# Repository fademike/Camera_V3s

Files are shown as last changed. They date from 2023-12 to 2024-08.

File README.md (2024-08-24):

# Camera_V3s
Webcam based on allwinner V3s and ESP8089

Simple 2 side board with Allwinner V3s, ov2640 and esp8089! 
(I didn't check the sound)

# How it works
Change wifi settings in file CONFIG_FILE <br>
Find ip in network by name. For example fing app: Image alt
<br>
Watch the video on the MXPlayer(rtsp://192.168.10.22:8554/test), ffmpeg (ffplay -i rtsp://192.168.10.22:8554/test).. <br>
Watch the video on the Gstreamer: gst-launch-1.0 rtspsrc location="rtsp://192.168.10.22:8554/test" latency=0 ! rtph264depay ! decodebin ! videoconvert ! ximagesink <br>

# for QGroundControl:
TX: gst-launch-1.0 -v v4l2src device=/dev/video0 ! "video/x-raw,format=UYVY,width=800,height=600,framerate=10/1" ! videoconvert ! cedar_h264enc bitrate=2000 qp=15 keyint=10 ! rtph264pay pt=96 ! udpsink host=192.168.10.14 port=5600 <br>
RX on QGC or gstreamer: gst-launch-1.0 -v udpsrc port=5600 ! "application/x-rtp, media=(string)video, clock-rate=(int)90000, encoding-name=(string)H264, payload=(int)96" ! rtph264depay ! h264parse ! avdec_h264 ! videoconvert ! autovideosink <br>

v1.4 changed scheme and pcb. didn't check <br>
v1.2 in the previous commit. it works but there are errors errataSheet.txt in kicad

top             |  bottom
:-------------------------:|:-------------------------:
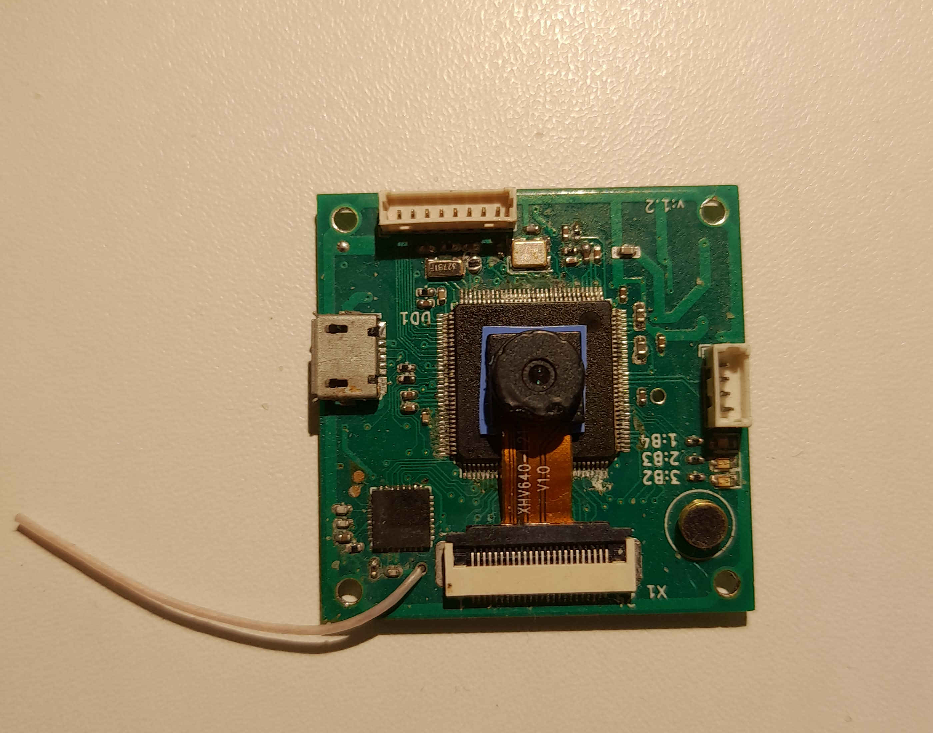
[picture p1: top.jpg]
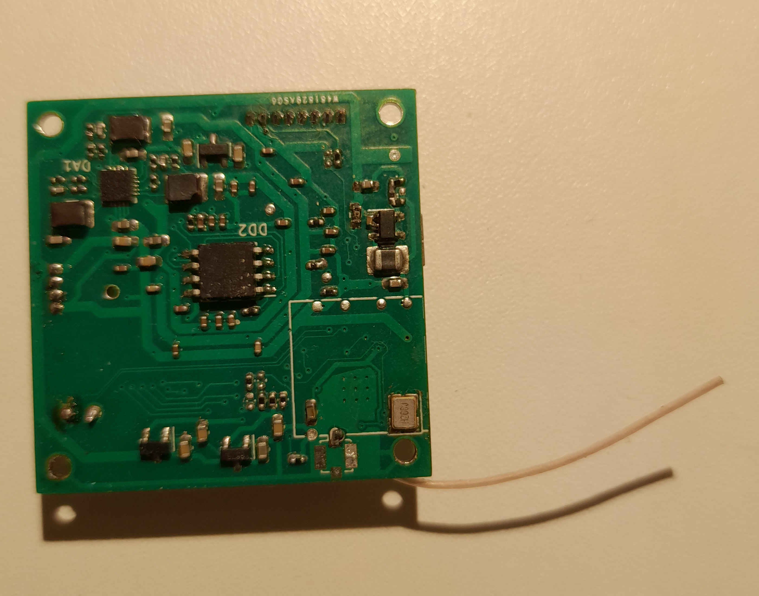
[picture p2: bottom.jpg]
  |  

# How to build

git clone https://github.com/fademike/buildroot_v3s.git <br>
tar xf ~/Downloads/buildroot-2023.08.tar.xz <br>
cd buildroot-2023.08 <br>
ln -s ~/Downloads/buildroot/dl ./dl  # if you want <br>
make BR2_EXTERNAL=../buildroot_v3s licheepi_zero_defconfig (in dts you can change size of NOR flash) <br>
make <br>
make esp-rebuild && make <br>

# How to install

insert sd card.. <br>
./make_sd.sh <br>
run board camera_v3s from flash <br>
mount /dev/mmcblk0p1 /mnt <br>
flashcp /mnt/uboot_spi.bin /dev/mtd0 -v <br>
flashcp /mnt/zImage /dev/mtd1 -v <br>
flashcp /mnt/uboot_spi.bin /dev/mtd2 -v <br>
flashcp /mnt/rootfs.squashfs /dev/mtd3 -v <br>
flash_erase /dev/mtd4 0 1000.. <br>
add to mtd4 CONFIG_FILE to wifi settings, and init/deinit script of system <br>
init.sh script for example: <br>
test-launch  --gst-debug=3 '( v4l2src device=/dev/video0 ! video/x-raw,format=UYVY,width=800,height=600,framerate=10/1 ! videoconvert ! cedar_h264enc bitrate=2000 qp=15 keyint=10 ! rtph264pay name=pay0 pt=96 )' &

# note

The wi-fi is crashes after 30-50min. It was discussed on the forum (https://whycan.com/t_4326.html). I would like to change it to XR819, 88W8801 or others. 
You can connect usb wifi adapter (such as MT7601U) or solder a USB wifi module on bottom side.
I didn't notice any problems with the usb wifi adapter.

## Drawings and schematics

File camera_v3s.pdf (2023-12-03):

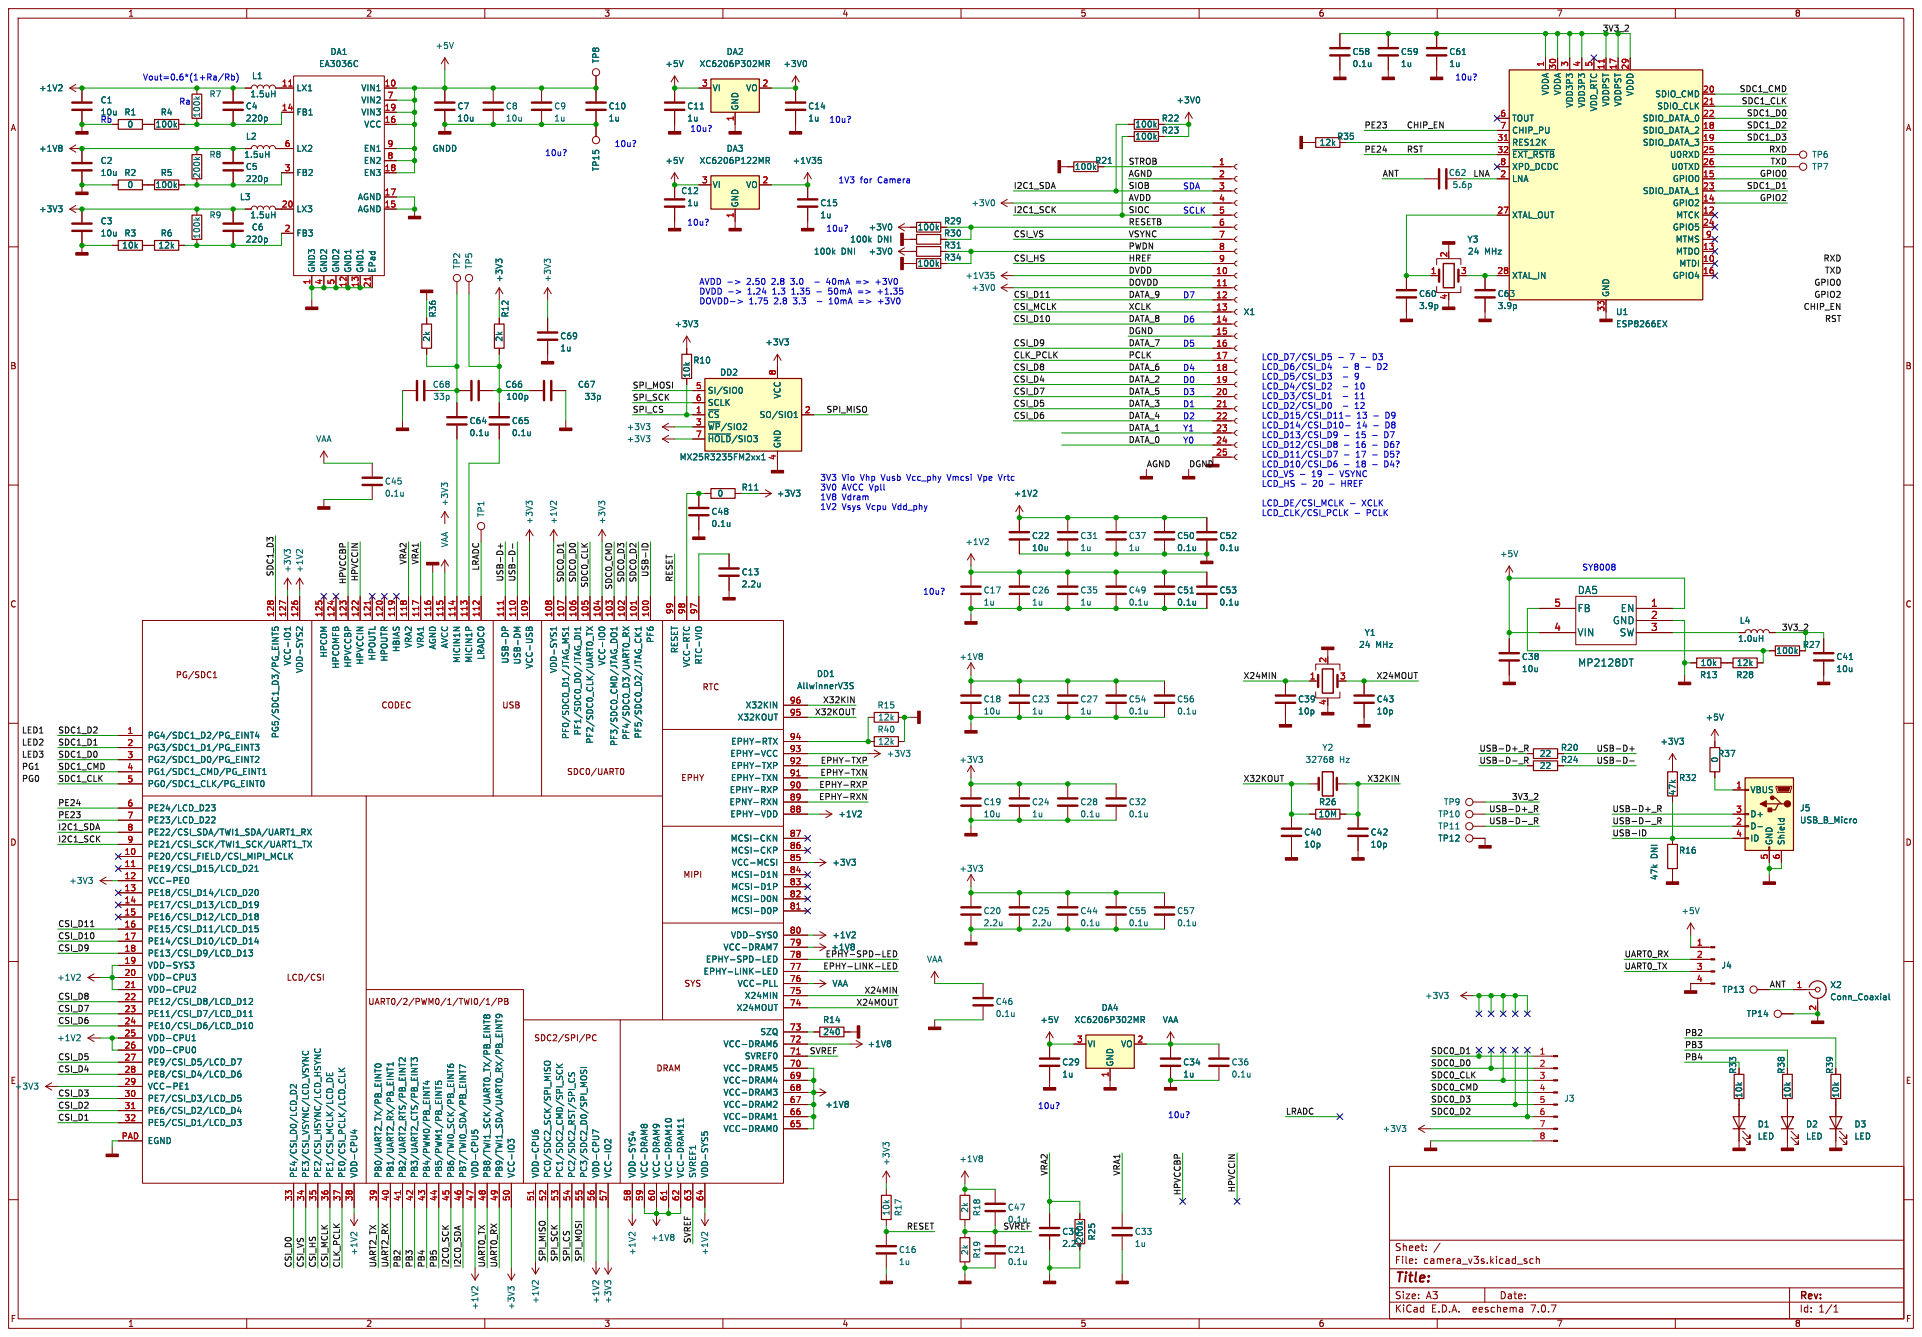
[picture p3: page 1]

4 SI/SIO0 5 SCLK 6 ~{HOLD}/SIO3 7 VCC

3V3 Vio Vhp Vusb Vcc_phy Vmcsi Vpe Vrtc 3V0 AVCC Vpll 1V8 Vdram

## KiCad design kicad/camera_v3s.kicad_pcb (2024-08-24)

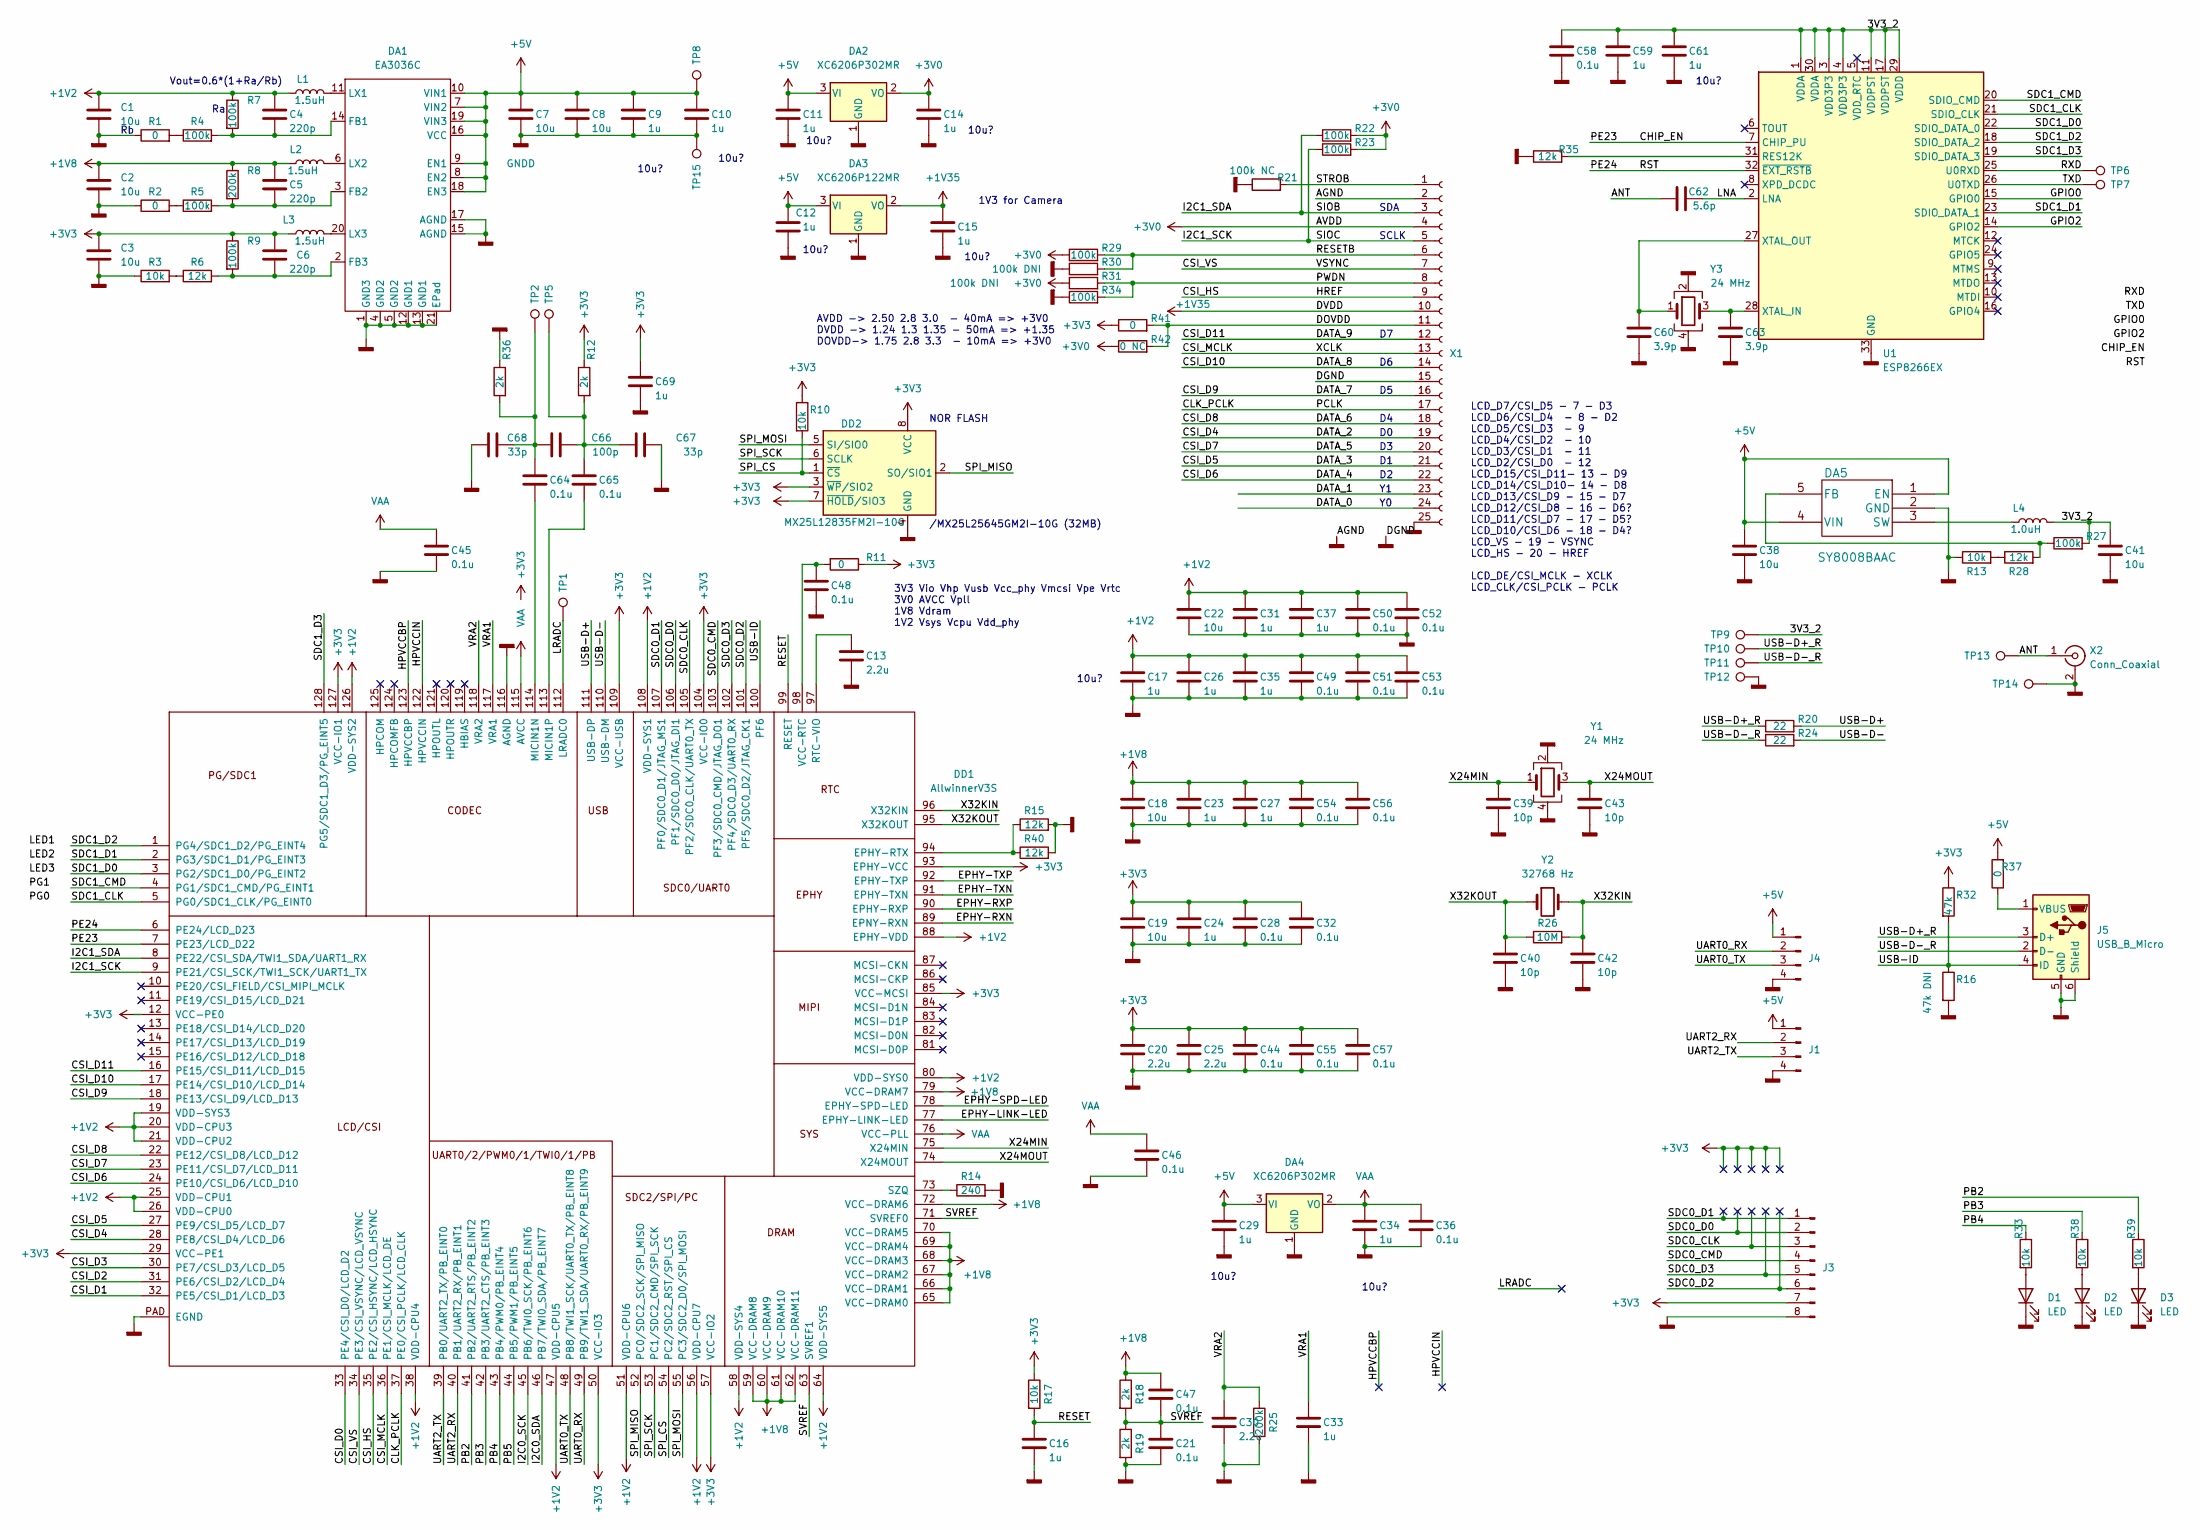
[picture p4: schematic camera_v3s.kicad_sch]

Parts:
C1, C2, C3, C7, C8, C18, C19, C22, C38, C41: 10u; C_0603_1608Metric; Voltage 6.3V
C4, C5, C6: 220p; C_0402_1005Metric; Voltage 6.3V
C9, C10, C11, C12, C14, C15, C16, C17, C23, C24, C26, C27, C29, C31, C33, C34, C35, C37, C59, C61, C69: 1u; C_0402_1005Metric; Voltage 6.3V
C13, C20, C25, C30: 2.2u; C_0402_1005Metric; Voltage 6.3V
C21, C28, C32, C36, C44, C45, C46, C47, C48, C49, C50, C51, C52, C53, C54, C55, C56, C57, C58, C64, C65: 0.1u; C_0402_1005Metric; Voltage 6.3V
C39, C40, C42, C43: 10p; C_0402_1005Metric; Voltage 6.3V
C60, C63: 3.9p; C_0402_1005Metric; Voltage 6.3V
C62: 5.6p; C_0402_1005Metric; Voltage 6.3V
C66: 100p; C_0402_1005Metric; Voltage 6.3V
C67, C68: 33p; C_0402_1005Metric; Voltage 6.3V
D1, D2, D3: LED; LED_0603_1608Metric
DA1: EA3036C; QFN-20-1EP_3x3mm_P0.4mm_EP1.65x1.65mm
DA2, DA4: XC6206P302MR; SOT-23
DA3: XC6206P122MR; SOT-23
DA5: SY8008BAAC; SOT-23-5
DD1: AllwinnerV3S; LQFP-128_14x14mm_P0.4mm
DD2: MX25L12835FM2I-10G; SOP-8_5.28x5.23mm_P1.27mm
J1, J4: Conn_01x04_Male; Molex_PicoBlade_53047-0410_1x04_P1.25mm_Vertical
J3: Conn_01x08_Male; Molex_PicoBlade_53047-0810_1x08_P1.25mm_Vertical
J5: USB_B_Micro; USB_Micro-B_Molex_47346-0001
L1, L2, L3: 1.5uH; L_1210_3225Metric
L4: 1.0uH; L_1210_3225Metric
R1, R2, R11, R41: 0; R_0402_1005Metric
R3, R10, R13, R17, R33, R38, R39: 10k; R_0402_1005Metric
R4, R5, R7, R9, R22, R23, R27, R29, R34: 100k; R_0402_1005Metric
R6, R15, R28, R35, R40: 12k; R_0402_1005Metric
R8, R25: 200k; R_0402_1005Metric
R12, R18, R19, R36: 2k; R_0402_1005Metric
R14: 240; R_0402_1005Metric
R16: 47k DNI; R_0402_1005Metric
R20, R24: 22; R_0402_1005Metric
R21: 100k NC; R_0402_1005Metric
R26: 10M; R_0402_1005Metric
R30, R31: 100k DNI; R_0402_1005Metric
R32: 47k; R_0402_1005Metric
R37: 0; R_0603_1608Metric
R42: 0 NC; R_0402_1005Metric
TP1, TP2, TP5, TP6, TP7, TP8, TP9, TP10, TP11, TP12, TP13, TP14, TP15: TestPoint; TestPoint_Pad_D1.0mm
U1: ESP8266EX; QFN-32-1EP_5x5mm_P0.5mm_EP3.45x3.45mm
X1: Conn_01x25_Female; CONN_FPC_24_0.5
X2: Conn_Coaxial; U.FL_Molex_MCRF_73412-0110_Vertical
Y1, Y3: 24 MHz; Crystal_SMD_3225-4Pin_3.2x2.5mm
Y2: 32768 Hz; Crystal_SMD_3215-2Pin_3.2x1.5mm

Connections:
+1V2: C1.1, C4.1, C17.1, C22.1, C26.1, C31.1, C35.1, C37.1, C49.1, C50.1, C51.1, C52.1, C53.1, DD1.19 (VDD-SYS3), DD1.20 (VDD-CPU3), DD1.21 (VDD-CPU2), DD1.25 (VDD-CPU1), DD1.26 (VDD-CPU0), DD1.38 (VDD-CPU4), DD1.47 (VDD-CPU5), DD1.51 (VDD-CPU6), DD1.56 (VDD-CPU7), DD1.58 (VDD-SYS4), DD1.64 (VDD-SYS5), DD1.80 (VDD-SYS0), DD1.88 (EPHY-VDD), DD1.108 (VDD-SYS1), DD1.126 (VDD-SYS2), L1.1, R7.1
+1V8: C2.1, C5.1, C18.1, C23.1, C27.1, C47.1, C54.1, C56.1, DD1.59 (VCC-DRAM8), DD1.60 (VCC-DRAM9), DD1.61 (VCC-DRAM10), DD1.62 (VCC-DRAM11), DD1.65 (VCC-DRAM0), DD1.66 (VCC-DRAM1), DD1.67 (VCC-DRAM2), DD1.68 (VCC-DRAM3), DD1.69 (VCC-DRAM4), DD1.70 (VCC-DRAM5), DD1.72 (VCC-DRAM6), DD1.79 (VCC-DRAM7), L2.1, R8.1, R18.1
+1V35: C15.1, DA3.2 (VO), X1.10
+3V0: C14.1, DA2.2 (VO), R22.2, R23.2, R29.1, R31.1, R42.1, X1.4
+3V3: C3.1, C6.1, C19.1, C20.1, C24.1, C25.1, C28.1, C32.1, C44.1, C55.1, C57.1, C69.1, DD1.12 (VCC-PE0), DD1.29 (VCC-PE1), DD1.50 (VCC-IO3), DD1.57 (VCC-IO2), DD1.85 (VCC-MCSI), DD1.93 (EPHY-VCC), DD1.104 (VCC-IO0), DD1.109 (VCC-USB), DD1.127 (VCC-IO1), DD2.3 (~WP/SIO2), DD2.7 (~HOLD/SIO3), DD2.8 (VCC), J3.7, L3.1, R9.1, R10.1, R11.1, R12.1, R17.1, R32.1, R41.1
+5V: C7.1, C8.1, C9.1, C10.1, C11.1, C12.1, C29.1, C38.1, DA1.7 (VIN2), DA1.8 (EN2), DA1.9 (EN1), DA1.10 (VIN1), DA1.16 (VCC), DA1.18 (EN3), DA1.19 (VIN3), DA2.3 (VI), DA3.3 (VI), DA4.3 (VI), DA5.1 (EN), DA5.4 (VIN), J1.1, J4.1, R37.2, TP8.1
/3V3_2: C41.1, C58.1, C59.1, C61.1, L4.2, R27.2, TP9.1, U1.1 (VDDA), U1.3 (VDD3P3), U1.4 (VDD3P3), U1.11 (VDDPST), U1.17 (VDDPST), U1.29 (VDDD), U1.30 (VDDA)
/ANT: C62.1, TP13.1, X2.1 (In)
/CHIP_EN: DD1.7 (PE23/LCD_D22), U1.7 (CHIP_PU)
/CLK_PCLK: DD1.37 (PE0/CSI_PCLK/LCD_CLK), X1.17
/CSI_D0: DD1.33 (PE4/CSI_D0/LCD_D2)
/CSI_D1: DD1.32 (PE5/CSI_D1/LCD_D3)
/CSI_D2: DD1.31 (PE6/CSI_D2/LCD_D4)
/CSI_D3: DD1.30 (PE7/CSI_D3/LCD_D5)
/CSI_D4: DD1.28 (PE8/CSI_D4/LCD_D6), X1.19
/CSI_D5: DD1.27 (PE9/CSI_D5/LCD_D7), X1.21
/CSI_D6: DD1.24 (PE10/CSI_D6/LCD_D10), X1.22
/CSI_D7: DD1.23 (PE11/CSI_D7/LCD_D11), X1.20
/CSI_D8: DD1.22 (PE12/CSI_D8/LCD_D12), X1.18
/CSI_D9: DD1.18 (PE13/CSI_D9/LCD_D13), X1.16
/CSI_D10: DD1.17 (PE14/CSI_D10/LCD_D14), X1.14
/CSI_D11: DD1.16 (PE15/CSI_D11/LCD_D15), X1.12
/CSI_HS: DD1.35 (PE2/CSI_HSYNC/LCD_HSYNC), X1.9
/CSI_MCLK: DD1.36 (PE1/CSI_MCLK/LCD_DE), X1.13
/CSI_VS: DD1.34 (PE3/CSI_VSYNC/LCD_VSYNC), X1.7
/DATA_0: X1.24
/DATA_1: X1.23
/DOVDD: R41.2, R42.2, X1.11
/EPHY-LINK-LED: DD1.77 (EPHY-LINK-LED)
/EPHY-RXN: DD1.89 (EPNY-RXN)
/EPHY-RXP: DD1.90 (EPHY-RXP)
/EPHY-SPD-LED: DD1.78 (EPHY-SPD-LED)
/EPHY-TXN: DD1.91 (EPHY-TXN)
/EPHY-TXP: DD1.92 (EPHY-TXP)
/GPIO0: U1.15 (GPIO0)
/GPIO2: U1.14 (GPIO2)
/HPVCCBP: DD1.123 (HPVCCBP)
/HPVCCIN: DD1.122 (HPVCCIN)
/I2C0_SCK: DD1.45 (PB6/TWI0_SCK/PB_EINT6)
/I2C0_SDA: DD1.46 (PB7/TWI0_SDA/PB_EINT7)
/I2C1_SCK: DD1.9 (PE21/CSI_SCK/TWI1_SCK/UART1_TX), R23.1, X1.5
/I2C1_SDA: DD1.8 (PE22/CSI_SDA/TWI1_SDA/UART1_RX), R22.1, X1.3
/LNA: C62.2, U1.2 (LNA)
/LRADC: DD1.112 (LRADC0), TP1.1
/PB2: DD1.41 (PB2/UART2_RTS/PB_EINT2), R39.1
/PB3: DD1.42 (PB3/UART2_CTS/PB_EINT3), R38.1
/PB4: DD1.43 (PB4/PWM0/PB_EINT4), R33.1
/PB5: DD1.44 (PB5/PWM1/PB_EINT5)
/PE24: DD1.6 (PE24/LCD_D23), U1.32 (~EXT_RSTB)
/PWDN: R31.2, R34.2, X1.8
/RESET: C16.1, DD1.99 (RESET), R17.2
/RESETB: R29.2, R30.2, X1.6
/RXD: TP6.1, U1.25 (U0RXD)
/SDC0_CLK: DD1.105 (PF2/SDC0_CLK/UART0_TX), J3.3
/SDC0_CMD: DD1.103 (PF3/SDC0_CMD/JTAG_DO1), J3.4
/SDC0_D0: DD1.106 (PF1/SDC0_D0/JTAG_DI1), J3.2
/SDC0_D1: DD1.107 (PF0/SDC0_D1/JTAG_MS1), J3.1
/SDC0_D2: DD1.101 (PF5/SDC0_D2/JTAG_CK1), J3.6
/SDC0_D3: DD1.102 (PF4/SDC0_D3/UART0_RX), J3.5
/SDC1_CLK: DD1.5 (PG0/SDC1_CLK/PG_EINT0), U1.21 (SDIO_CLK)
/SDC1_CMD: DD1.4 (PG1/SDC1_CMD/PG_EINT1), U1.20 (SDIO_CMD)
/SDC1_D0: DD1.3 (PG2/SDC1_D0/PG_EINT2), U1.22 (SDIO_DATA_0)
/SDC1_D1: DD1.2 (PG3/SDC1_D1/PG_EINT3), U1.23 (SDIO_DATA_1)
/SDC1_D2: DD1.1 (PG4/SDC1_D2/PG_EINT4), U1.18 (SDIO_DATA_2)
/SDC1_D3: DD1.128 (PG5/SDC1_D3/PG_EINT5), U1.19 (SDIO_DATA_3)
/SPI_CS: DD1.54 (PC2/SDC2_RST/SPI_CS), DD2.1 (~CS), R10.2
/SPI_MISO: DD1.52 (PC0/SDC2_SCK/SPI_MISO), DD2.2 (SO/SIO1)
/SPI_MOSI: DD1.55 (PC3/SDC2_D0/SPI_MOSI), DD2.5 (SI/SIO0)
/SPI_SCK: DD1.53 (PC1/SDC2_CMD/SPI_SCK), DD2.6 (SCLK)
/STROB: R21.2, X1.1
/SVREF: C21.1, C47.2, DD1.63 (SVREF1), DD1.71 (SVREF0), R18.2, R19.1
/TXD: TP7.1, U1.26 (U0TXD)
/UART0_RX: DD1.49 (PB9/TWI1_SDA/UART0_RX/PB_EINT9), J4.2
/UART0_TX: DD1.48 (PB8/TWI1_SCK/UART0_TX/PB_EINT8), J4.3
/UART2_RX: DD1.40 (PB1/UART2_RX/PB_EINT1), J1.2
/UART2_TX: DD1.39 (PB0/UART2_TX/PB_EINT0), J1.3
/USB-D+: DD1.111 (USB-DP), R20.2
/USB-D+_R: J5.3 (D+), R20.1, TP10.1
/USB-D-: DD1.110 (USB-DM), R24.2
/USB-D-_R: J5.2 (D-), R24.1, TP11.1
/USB-ID: DD1.100 (PF6), J5.4 (ID), R16.1, R32.2
/VRA1: C33.1, DD1.117 (VRA1)
/VRA2: C30.1, DD1.118 (VRA2), R25.1
/X24MIN: C39.1, DD1.75 (X24MIN), Y1.1
/X24MOUT: C43.1, DD1.74 (X24MOUT), Y1.3
/X32KIN: C42.1, DD1.96 (X32KIN), R26.2, Y2.2
/X32KOUT: C40.1, DD1.95 (X32KOUT), R26.1, Y2.1
GNDD: C1.2, C2.2, C3.2, C7.2, C8.2, C9.2, C10.2, C11.2, C12.2, C13.2, C14.2, C15.2, C16.2, C17.2, C18.2, C19.2, C20.2, C21.2, C22.2, C23.2, C24.2, C25.2, C26.2, C27.2, C28.2, C29.2, C30.2, C31.2, C32.2, C33.2, C34.2, C35.2, C36.2, C37.2, C38.2, C39.2, C40.2, C41.2, C42.2, C43.2, C44.2, C45.2, C46.2, C48.2, C49.2, C50.2, C51.2, C52.2, C53.2, C54.2, C55.2, C56.2, C57.2, C58.2, C59.2, C60.2, C61.2, C63.2, C67.2, C68.1, C69.2, D1.1 (K), D2.1 (K), D3.1 (K), DA1.1 (GND3), DA1.4 (GND2), DA1.5 (GND2), DA1.12 (GND1), DA1.13 (GND1), DA1.15 (AGND), DA1.17 (AGND), DA1.21 (EPad), DA2.1 (GND), DA3.1 (GND), DA4.1 (GND), DA5.2 (GND), DD1.116 (AGND), DD1.PAD (EGND), DD2.4 (GND), J1.4, J3.8, J4.4, J5.5 (GND), J5.6 (Shield), R1.1, R2.1, R3.1, R13.1, R14.2, R15.2, R16.2, R19.2, R21.1, R25.2, R30.1, R34.1, R35.1, R36.1, R40.2, TP12.1, TP14.1, TP15.1, U1.33 (GND), X1.2, X1.15, X1.25, X2.2 (Ext), Y1.2, Y1.4, Y3.2, Y3.4
unnamed: C64.1, C66.1, C68.2, R36.2, TP2.1
unnamed: C65.1, C66.2, C67.1, R12.2, TP5.1
unnamed: D1.2 (A), R33.2
unnamed: D2.2 (A), R38.2
unnamed: D3.2 (A), R39.2
unnamed: C4.2, DA1.14 (FB1), R4.2, R7.2
unnamed: C5.2, DA1.3 (FB2), R5.2, R8.2
unnamed: C6.2, DA1.2 (FB3), R6.2, R9.2
unnamed: DA1.11 (LX1), L1.2
unnamed: DA1.6 (LX2), L2.2
unnamed: DA1.20 (LX3), L3.2
unnamed: DA5.5 (FB), R27.1, R28.2
unnamed: DA5.3 (SW), L4.1
unnamed: DD1.94 (EPHY-RTX), R15.1, R40.1
unnamed: C64.2, DD1.114 (MICIN1N)
unnamed: C65.2, DD1.113 (MICIN1P)
unnamed: C13.1, DD1.97 (RTC-VIO)
unnamed: DD1.73 (SZQ), R14.1
unnamed: C48.1, DD1.98 (VCC-RTC), R11.2
unnamed: J5.1 (VBUS), R37.1
unnamed: R1.2, R4.1
unnamed: R2.2, R5.1
unnamed: R3.2, R6.1
unnamed: R13.2, R28.1
unnamed: R35.2, U1.31 (RES12K)
unnamed: C63.1, U1.28 (XTAL_IN), Y3.3
unnamed: C60.1, U1.27 (XTAL_OUT), Y3.1
VAA: C34.1, C36.1, C45.1, C46.1, DA4.2 (VO), DD1.76 (VCC-PLL), DD1.115 (AVCC)

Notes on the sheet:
10u?
3V3 Vio Vhp Vusb Vcc_phy Vmcsi Vpe Vrtc 3V0 AVCC Vpll 1V8 Vdram 1V2 Vsys Vcpu Vdd_phy
SCLK
1V3 for Camera
AVDD -> 2.50 2.8 3.0 - 40mA => +3V0 DVDD -> 1.24 1.3 1.35 - 50mA => +1.35 DOVDD-> 1.75 2.8 3.3 - 10mA => +3V0
NOR FLASH
LCD_D7/CSI_D5 - 7 - D3 LCD_D6/CSI_D4 - 8 - D2 LCD_D5/CSI_D3 - 9 LCD_D4/CSI_D2 - 10 LCD_D3/CSI_D1 - 11 LCD_D2/CSI_D0 - 12 LCD_D15/CSI_D11- 13 - D9 LCD_D14/CSI_D10- 14 - D8 LCD_D13/CSI_D9 - 15 - D7 LCD_D12/CSI_D8 - 16 - D6? LCD_D11/CSI_D7 - 17 - D5? LCD_D10/CSI_D6 - 18 - D4? LCD_VS - 19 - VSYNC LCD_H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
Vout=0.6*(1+Ra/Rb)
SDA
/MX25L25645GM2I-10G (32MB)

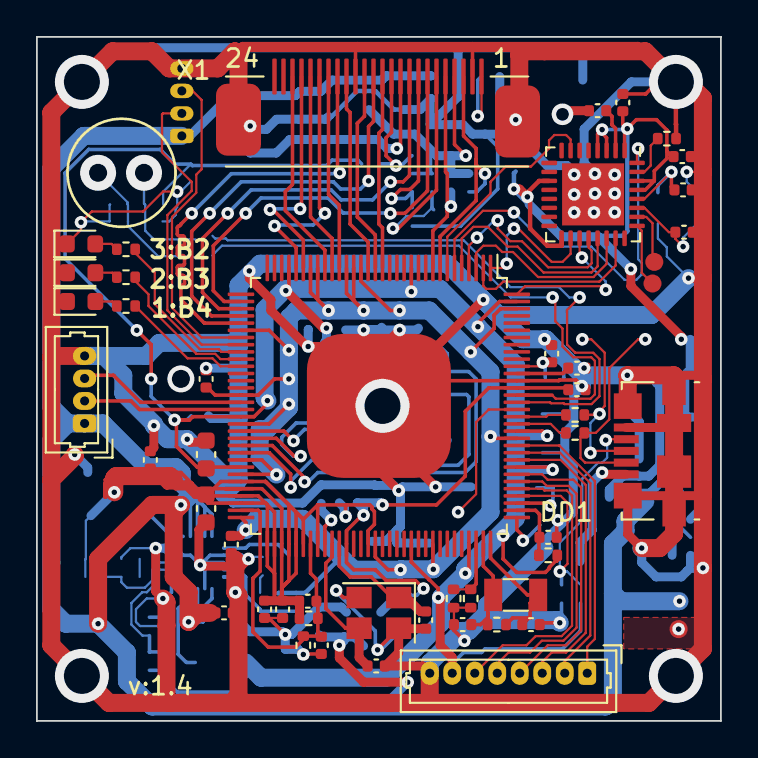
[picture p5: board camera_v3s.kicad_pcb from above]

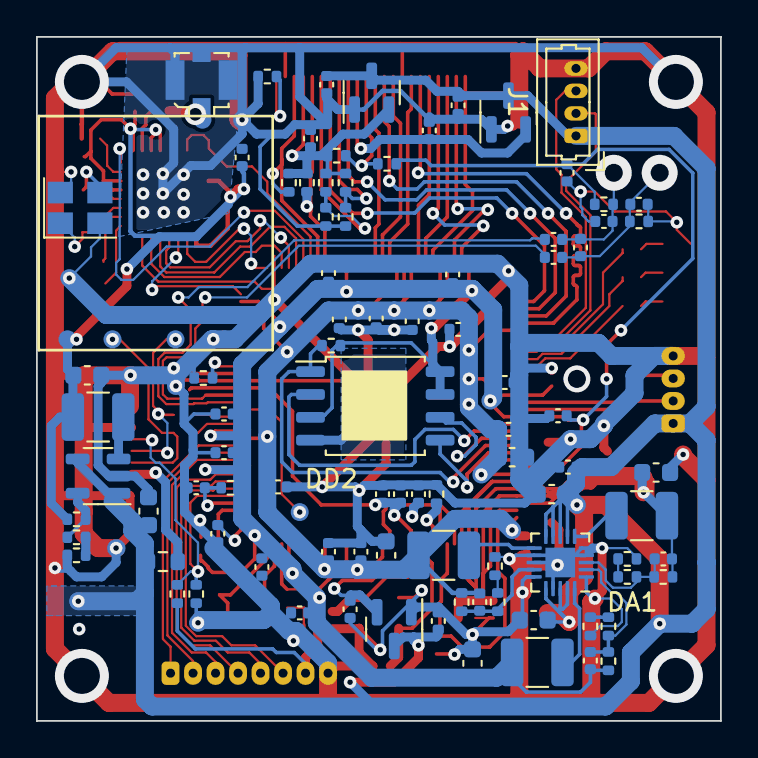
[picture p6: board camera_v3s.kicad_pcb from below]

Board: 2 copper layers, 38.0 x 38.0 mm, 148 parts (97 on the bottom side), 97 nets.

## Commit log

2023-12-03 v1.2 uploaded
    [camera_v3s-B_Cu.gbr, camera_v3s-B_Mask.gbr, camera_v3s-B_Paste.gbr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]
2023-12-03 v1.4 changed scheme and pcb. did not tested version
    [camera_v3s-B_Cu.gbr, camera_v3s-B_Mask.gbr, camera_v3s-B_Paste.gbr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]
2024-08-24 notes on wifi
    [camera_v3s.kicad_pcb, camera_v3s.kicad_sch]
